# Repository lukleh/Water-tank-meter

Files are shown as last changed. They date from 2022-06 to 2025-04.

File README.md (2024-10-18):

# Water tank meter

ESP8266 based project for measuring water level in tank using ultrasonic sensor complete with 3D printed enclosure accesible through web interface.

You need to install [ESPHome](https://esphome.io/)
```
esphome run studna.yaml
```
Use silicone to seal the box.

## Hardware
* [WeMos D1 Mini Pro 16MB ESP8266 WiFi modul](https://www.laskakit.cz/wemos-d1-mini-pro--esp8266-wifi-modul/)
* [Bi-Directional Logic Level Converter (4 Channel) 5v 3.3v](https://www.laskakit.cz/4-kanaly-obousmerny-prevodnik-logickych-urovni-5v-a-3-3v/)
* [Pigtail U.FL - RP-SMA Female, kabel 1,15mm, 15cm](https://www.laskakit.cz/pigtail-u-fl-rp-sma-female--kabel-1-13mm--18cm/)
* [MaxLink alldirection anthena, 10dBi, 2.4GHz, RSMA](https://www.suntech.cz/maxlink-vsesmerova-antena-10dbi-2-4ghz-rsma_d152907.html)
* [microUSB charger](https://www.laskakit.cz/napajeci-adapter-sitovy-3a-5v-pro-raspberry-pi-microusb/)
* [prototype pcb board](https://www.laskakit.cz/50x70mm-pcb-prototypova-deska/)

## Wiring diagram

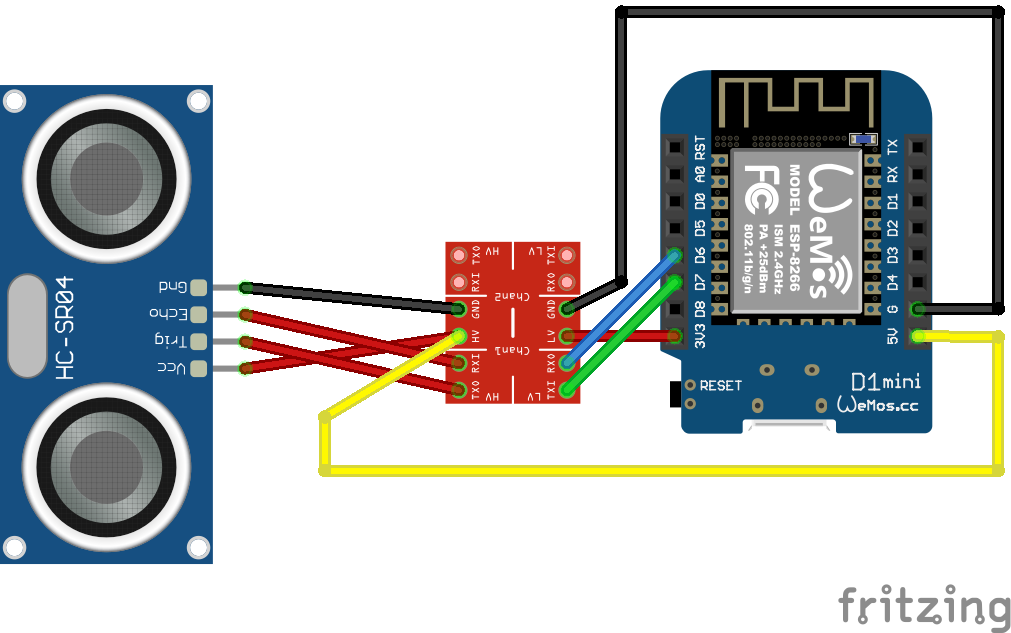
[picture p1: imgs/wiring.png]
Wiring diagram


## Photo details
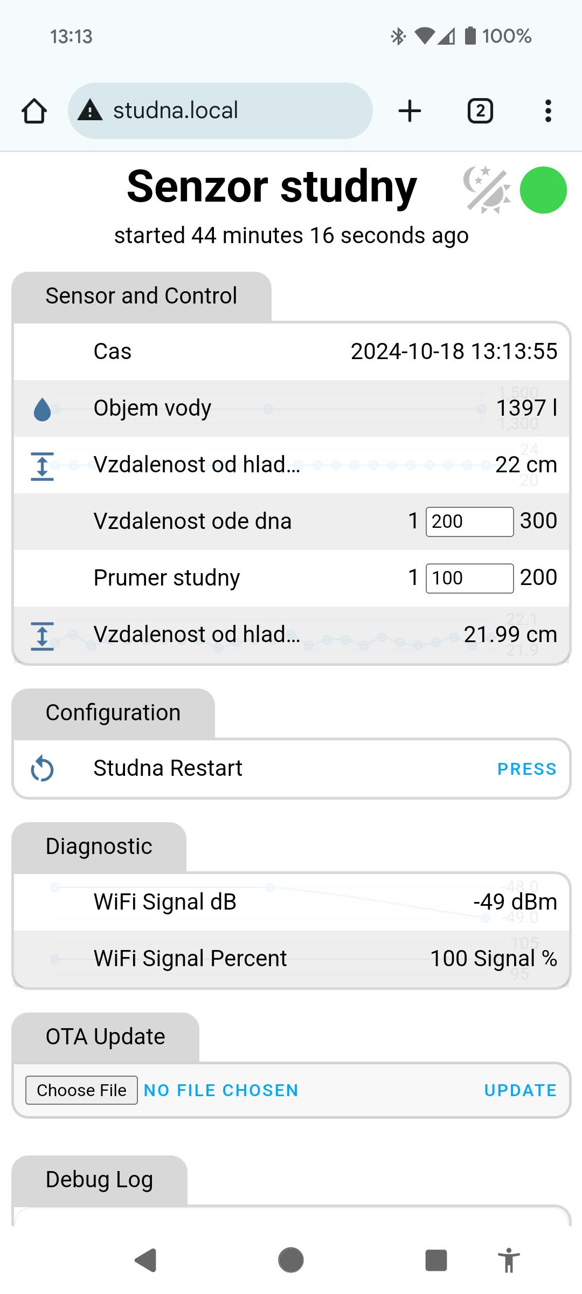
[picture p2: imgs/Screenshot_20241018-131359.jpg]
Mobile screenshot

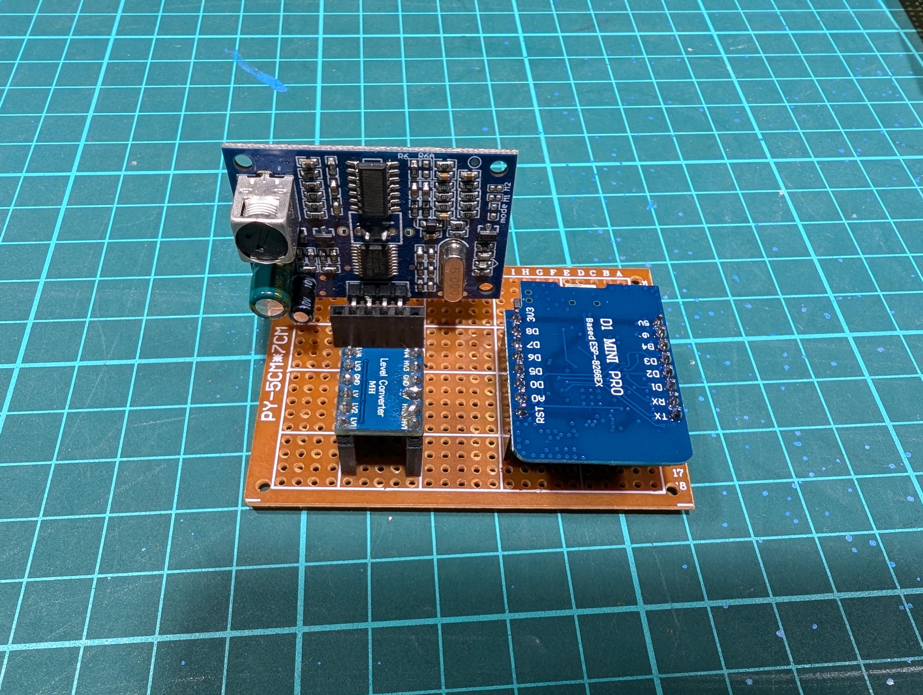
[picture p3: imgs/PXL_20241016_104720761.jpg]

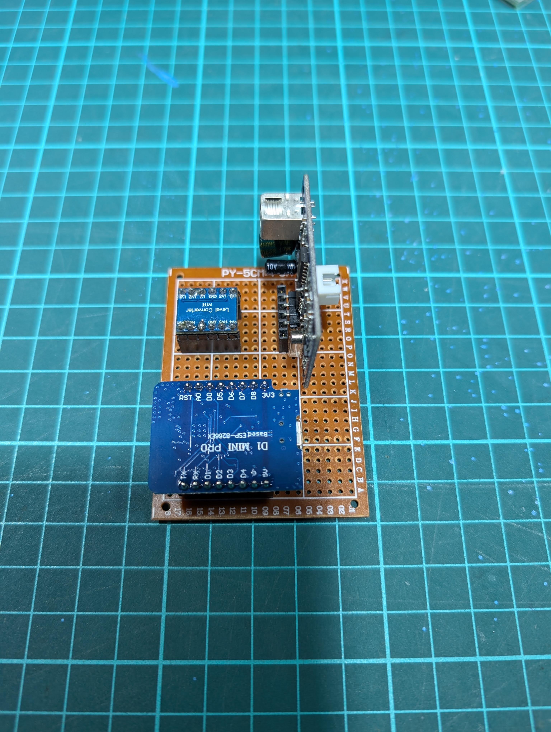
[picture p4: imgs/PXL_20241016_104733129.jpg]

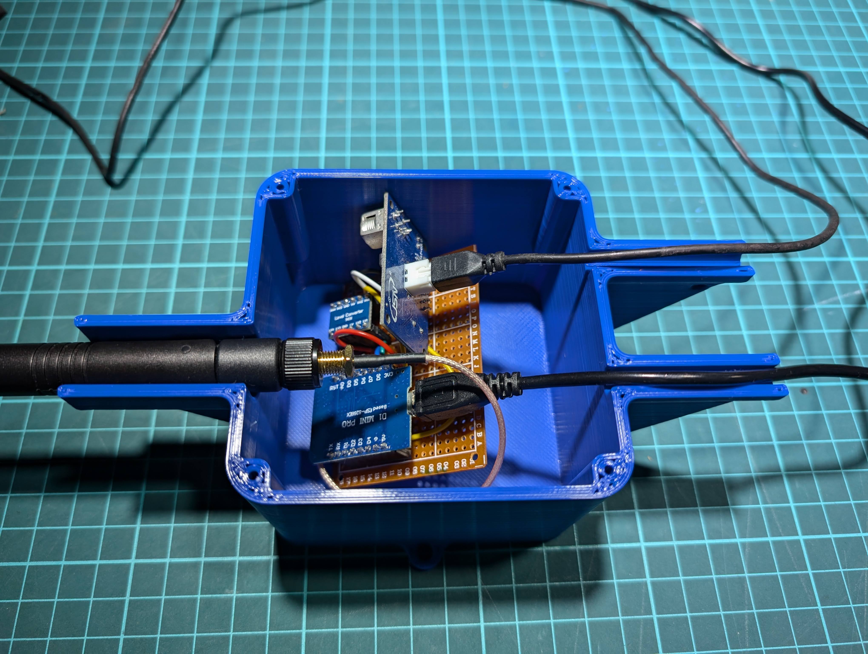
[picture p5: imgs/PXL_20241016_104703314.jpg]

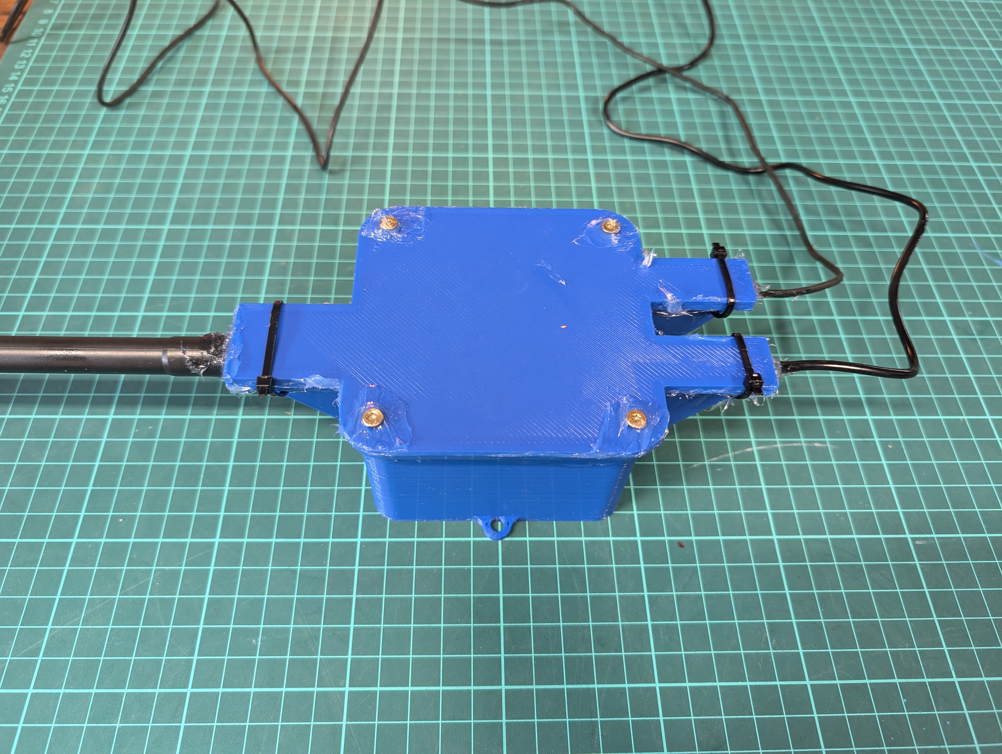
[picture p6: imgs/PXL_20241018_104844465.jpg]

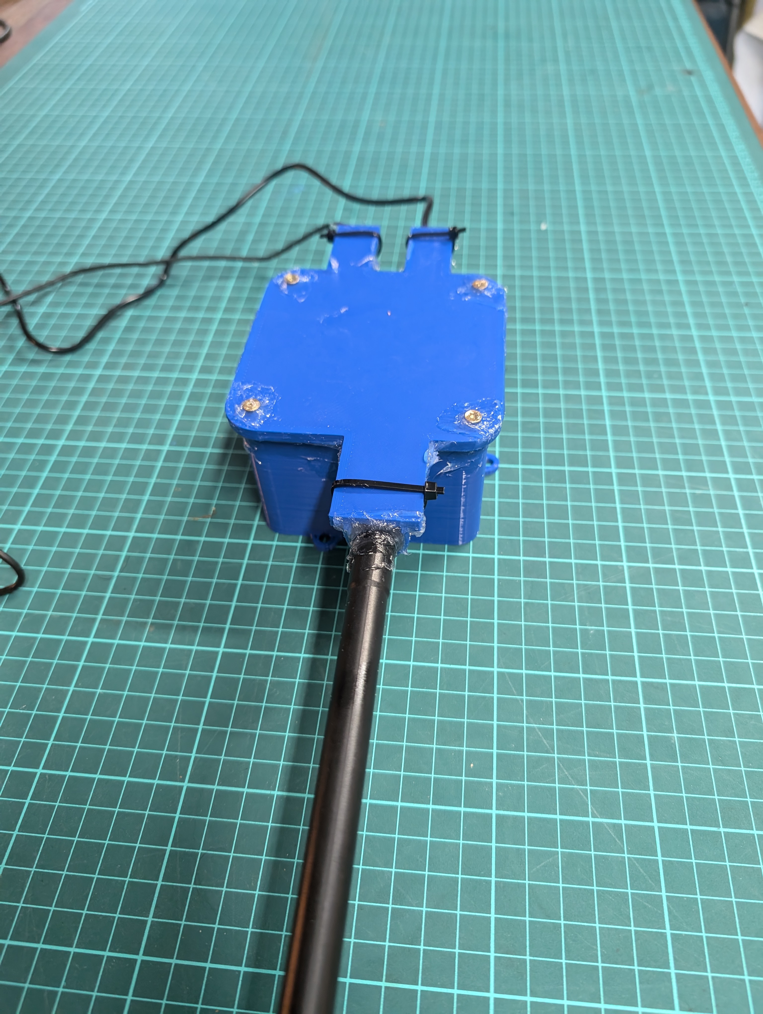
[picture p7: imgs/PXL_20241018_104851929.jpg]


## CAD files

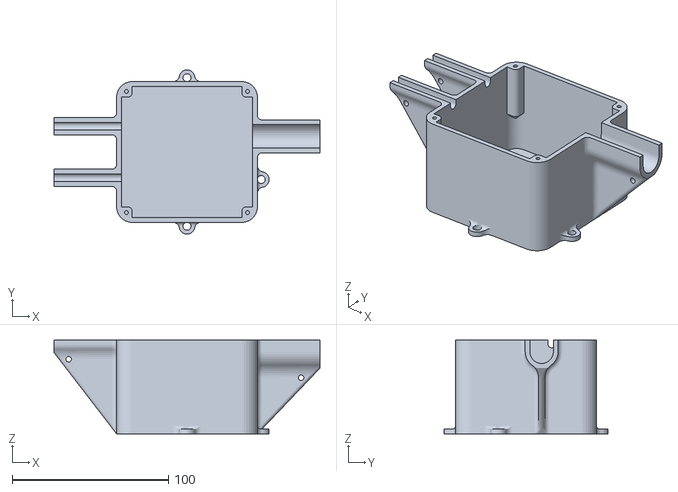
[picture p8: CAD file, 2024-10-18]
STL/water tank sensor box.stl
170.0 x 104.9 x 60.0

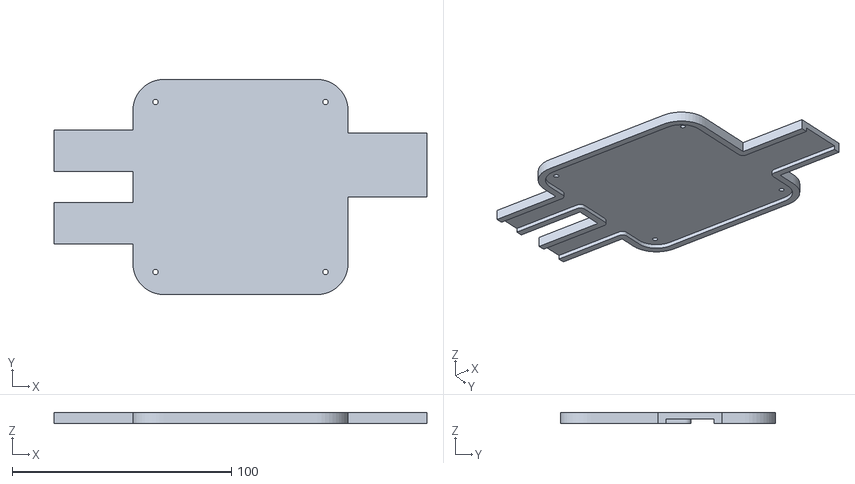
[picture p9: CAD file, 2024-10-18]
STL/water tank sensor lid.stl
170.0 x 98.0 x 5.00

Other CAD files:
STL/Water tank sensor enclosure v7.f3d

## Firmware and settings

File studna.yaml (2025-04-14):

esphome:
  name: studna
  friendly_name: "Senzor studny"
  area: zahrada

esp8266:
  board: d1_mini_pro
  restore_from_flash: true

logger:
  level: INFO

wifi:
  ssid: !secret wifi_ssid
  password: !secret wifi_password
  ap: {}

ota:
  platform: esphome

captive_portal:

web_server:
  port: 80
  version: 3
  log: true

time:
  - platform: sntp
    id: sntp_time
    timezone: Europe/Prague
    on_time_sync:
      then:
        - logger.log: "Synchronized system clock"

text_sensor:
  - platform: template
    id: show_time
    name: "Cas"
    web_server:
      sorting_weight: 2

  - platform: wifi_info
    ip_address:
      name: "WiFi IP Address"
      id: wifi_ip
      web_server:
        sorting_weight: 70

sensor:
  - platform: ultrasonic
    trigger_pin: D7
    echo_pin: D6
    name: "Vzdalenost od hladiny ted"
    id: vzdalenost
    unit_of_measurement: "cm"
    update_interval: 1s
    filters:
      - lambda: return x * 100;
    web_server:
      sorting_weight: 49

  - platform: copy
    source_id: vzdalenost
    name: "Vzdalenost od hladiny prumer"
    id: vzdalenost_prumer
    unit_of_measurement: "cm"
    accuracy_decimals: 0
    filters:
      - sliding_window_moving_average:
          window_size: 10
          send_every: 1
      - filter_out: nan
      - lambda: return round(x);
    web_server:
      sorting_weight: 10

  - platform: copy
    source_id: vzdalenost_prumer
    name: "Objem vody"
    id: objem_vody
    icon: "mdi:water"
    unit_of_measurement: "l"
    accuracy_decimals: 0
    filters:
      - sliding_window_moving_average:
          window_size: 30
          send_every: 10
      - filter_out: nan
      - lambda: return round((3.14 * (id(prumer).state / 2.0) * (id(prumer).state / 2.0) * (id(hloubka).state - x)) / 1000) ;
    web_server:
      sorting_weight: 5


  - platform: wifi_signal
    name: "WiFi Signal dB"
    id: wifi_signal_db
    update_interval: 10s
    entity_category: "diagnostic"
    web_server:
      sorting_weight: 32

  - platform: copy
    source_id: wifi_signal_db
    name: "WiFi Signal Percent"
    filters:
      - lambda: return min(max(2 * (x + 100.0), 0.0), 100.0);
    unit_of_measurement: "Signal %"
    entity_category: "diagnostic"
    device_class: ""
    web_server:
      sorting_weight: 34
    
number:
  - platform: template
    name: "Vzdalenost ode dna"
    id: hloubka
    optimistic: true
    min_value: 1
    max_value: 300
    initial_value: 200
    step: 1
    restore_value: true
    mode: box
    device_class: distance
    web_server:
      sorting_weight: 20

  - platform: template
    name: "Prumer studny"
    id: prumer
    optimistic: true
    min_value: 1
    max_value: 200
    initial_value: 150
    step: 1
    restore_value: true
    mode: box
    device_class: distance
    web_server:
      sorting_weight: 30

  - platform: template
    name: "Log Level"
    id: log_level
    optimistic: true
    min_value: 0
    max_value: 3
    step: 1
    initial_value: 1  # Start at 'Errors only'
    restore_value: true
    web_server:
      sorting_weight: 60
    mode: slider
    unit_of_measurement: "Level"
    on_value:
      then:
        - lambda: |-
            int logLevel = int(id(log_level).state);
            ESP_LOGI("custom", "Log level changed to %d", logLevel);

button:
  - platform: restart
    name: "Studna Restart"
    web_server:
      sorting_weight: 40

interval:
  - interval: 1s
    then:
      - lambda: |-
          // Log level meanings:
          // 0 = Silent
          // 1 = Errors only
          // 2 = Normal (Info)
          // 3 = Verbose / Debug

          // Read log level state
          int logLevel = int(id(log_level).state);
          
          auto time = id(sntp_time).now();
          char strftime_buf[64];
          time.strftime(strftime_buf, sizeof(strftime_buf), "%Y-%m-%d %H:%M:%S");
          id(show_time).publish_state(strftime_buf);

          // Only execute if log level is normal or verbose
          if (logLevel == 3) {
            ESP_LOGI("custom", "Verbose: Time updated to %s", strftime_buf);
            // Log all sensors manually at verbose level
            ESP_LOGI("custom", "Sensor - Vzdalenost ted: %.2f cm", id(vzdalenost).state);
            ESP_LOGI("custom", "Sensor - Vzdalenost prumer: %.2f cm", id(vzdalenost_prumer).state);
            ESP_LOGI("custom", "Sensor - WiFi Signal dB: %.2f dB", id(wifi_signal_db).state);
            ESP_LOGI("custom", "Sensor - Objem vody: %.2f l", id(objem_vody).state);
          }

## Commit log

2022-05-08 add 3D models
    [sensor box.stl, sensor cover.stl, water tank sensor enclosure.f3d]
2022-05-08 more reliable sensor reading
2022-05-15 better wiring + wifi null check
2022-05-21 stable sync
    [sensor box.3mf, sensor box.stl, sensor cover.3mf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]
2022-05-23 v1.1 cleaned up + fixes
    [sensor box antenna.stl, sensor cover.3mf]
2022-05-24 include board name + fixes
2022-06-02 cleaning and readme
    [sensor box.3mf, sensor cover.3mf]
2022-06-02 el parts
2022-06-02 screw length
2022-06-07 accuracy tweaks
    sensor has 1cm accuracy, but we can lean on mean to go 1mm measurements
2024-10-18 esphome version
    [Water tank sensor enclosure v7.f3d, sensor box antenna.stl, sensor box.stl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]
2025-03-06 bump up ESPHome to 2025.2.2, OTA fix
    [studna.yaml]
2025-04-14 Add WiFi IP address sensor configuration to studna.yaml
